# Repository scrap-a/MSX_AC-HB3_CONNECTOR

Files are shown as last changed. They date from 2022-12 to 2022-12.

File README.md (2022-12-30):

# MSX_AC-HB3_CONNECTOR
SONY製（HB-F1など）やPanasonic製（FS-A1など）の一部MSX機種で採用されている、特殊な形状のACアダプタのコネクタ部分について3Dモデルとして試作してみたものです。SONY製の場合のACアダプタの型番はAC-HB3の模様です（未所有）。

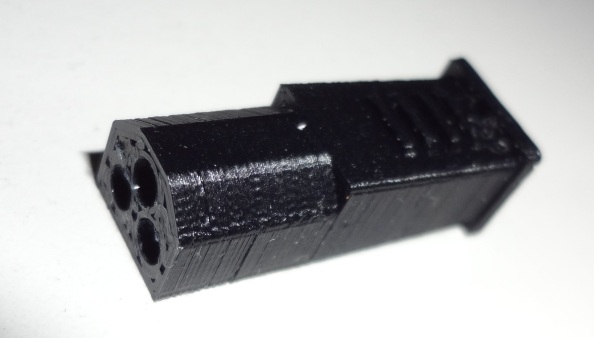
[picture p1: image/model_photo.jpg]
overview image


# 特殊な形状のACアダプタコネクタ
入力電圧（DC9VとAC18Vの両方）も特殊ながら、コネクタが市販されていない形状であり補修が難しいです。

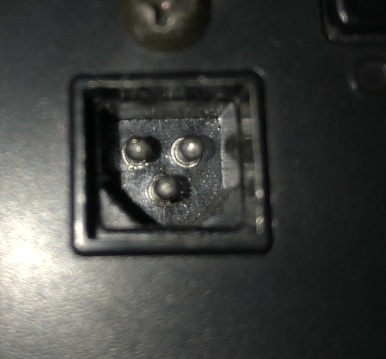
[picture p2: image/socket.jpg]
overview image


# 注意事項
当方は3Dモデリングも3Dプリンタ利用も初めてで、対象のACアダプター自体も所有していないため、形状の測定も設計もいい加減です。<br>
また、3Dプリンタ自体も所有していないので、あまり試行錯誤もできていません。<br>
本モデルを利用してソケット部分が故障したりしても責任は取れません。可能であれば、改善版を共有頂けますとありがたいです。

# 電気的に接続する部分について
AliExpressで購入した2mmΦのバナナプラグ（メス側）を使用しています。<br>
購入したSHOP:https://ja.aliexpress.com/item/4000439855711.html<br>

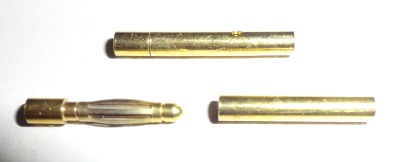
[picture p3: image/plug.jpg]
overview image


精度にバラツキがあるので、ちゃんと受け口にしっかりハマるものを選びます。<br>
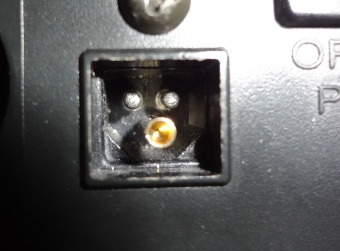
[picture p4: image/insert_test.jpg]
overview image


# モデルについて
OpenSCADで設計しました。srcディレクトリ内にソースも共有しています。モデルのSTLはstlディレクトリにあります。<br>
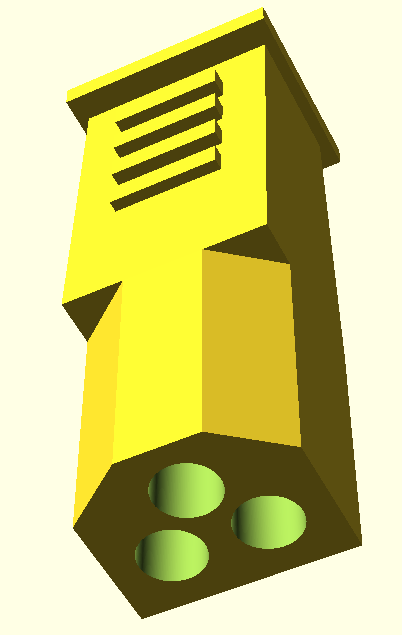
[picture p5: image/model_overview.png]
overview image


穴の部分については、バナナプラグ用の穴と細い穴をつなげて、ケーブルだけが接続できるようにしています。<br>
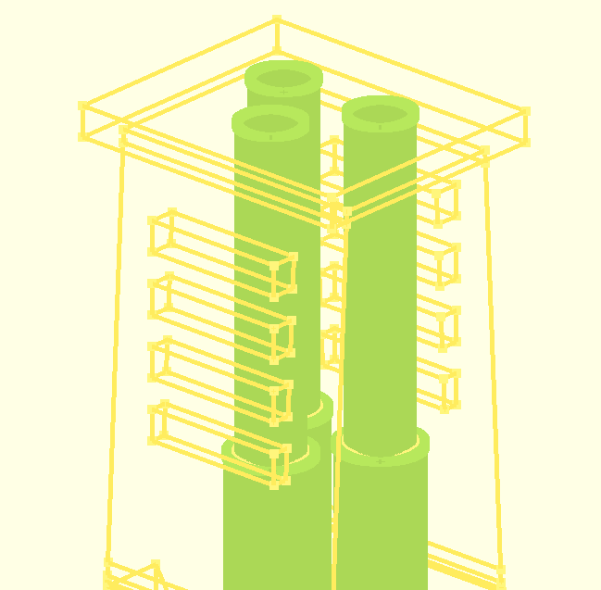
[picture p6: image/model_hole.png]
overview image


緑色がモデルにあいている穴で、下側の太い方がバナナプラグ用です。

# ケーブルなどの接続について
DC9VとAC18Vの電源をどのように準備するか、どのように接続するかなどの説明はしません。あくまでコネクタのモデルを3Dプリントしたあとどのように扱うかの手順です。<br>
1. あらかじめケーブルを通してバナナプラグ（メス側）にはんだ付けします。<br>
このとき3Dプリントしたモデルは熱に弱いので気を付けること。<br>
接合部は、はんだ付けだけでなくレジンなどで固めた方がいいかも知れませんが、はみ出すとモデル部に収まらなくなります。<br>
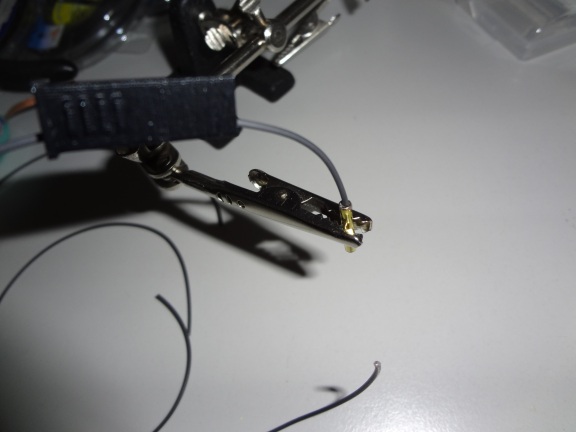
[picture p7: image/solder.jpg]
overview image

2. 穴の部分にバナナプラグを押し込みます。<br>
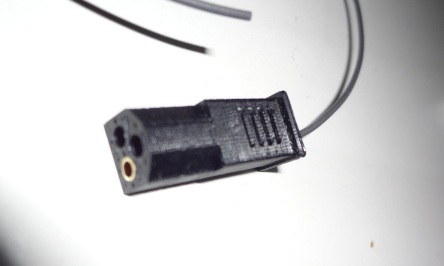
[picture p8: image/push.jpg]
overview image

3. ケーブルを電源プラグの受け口などと接続したら完成です。<br>
必要に応じて接合部を熱収縮チューブで覆うなど処理してください。<br>
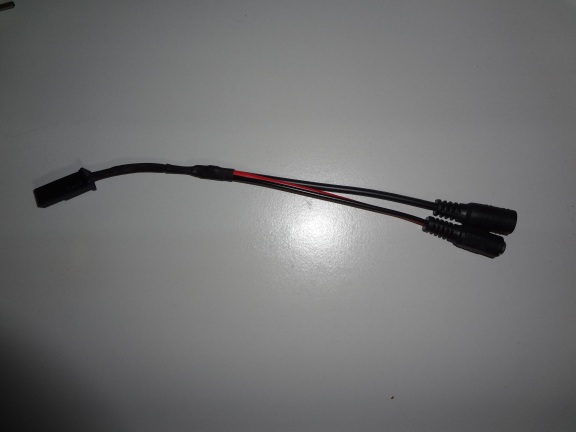
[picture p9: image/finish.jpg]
overview image


# 完成品の画像
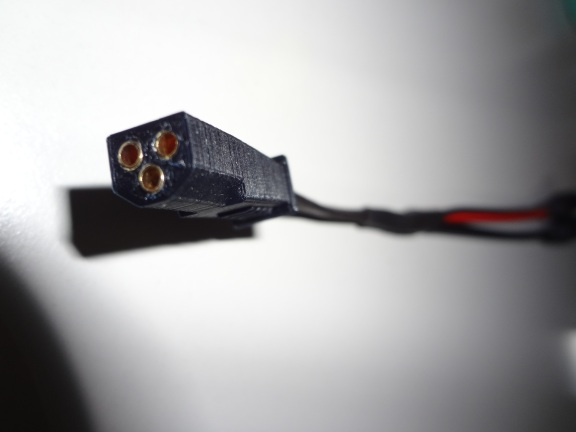
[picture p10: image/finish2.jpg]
overview image

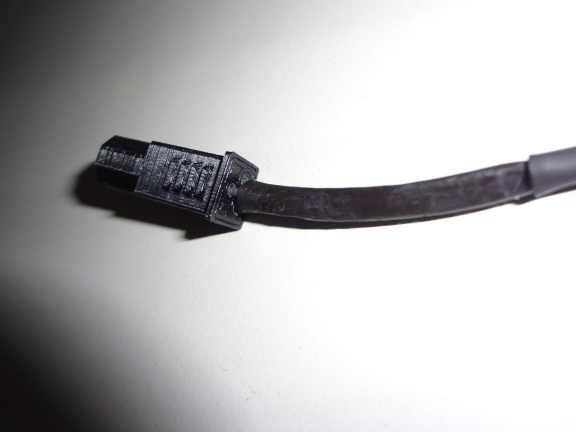
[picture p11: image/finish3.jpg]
overview image

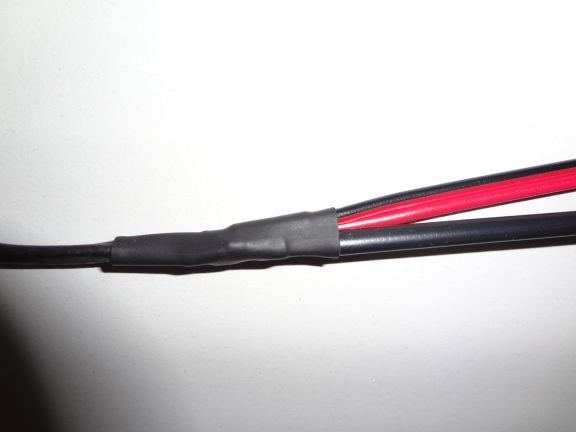
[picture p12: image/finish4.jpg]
overview image

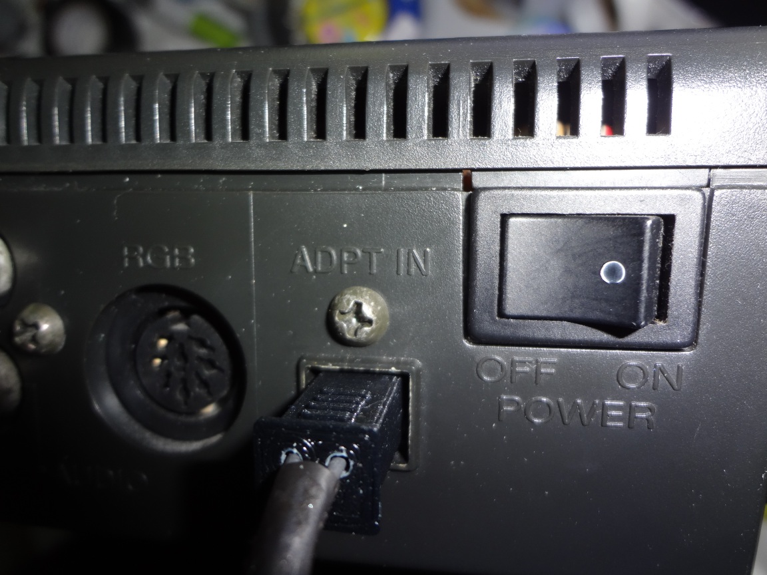
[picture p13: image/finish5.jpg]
overview image

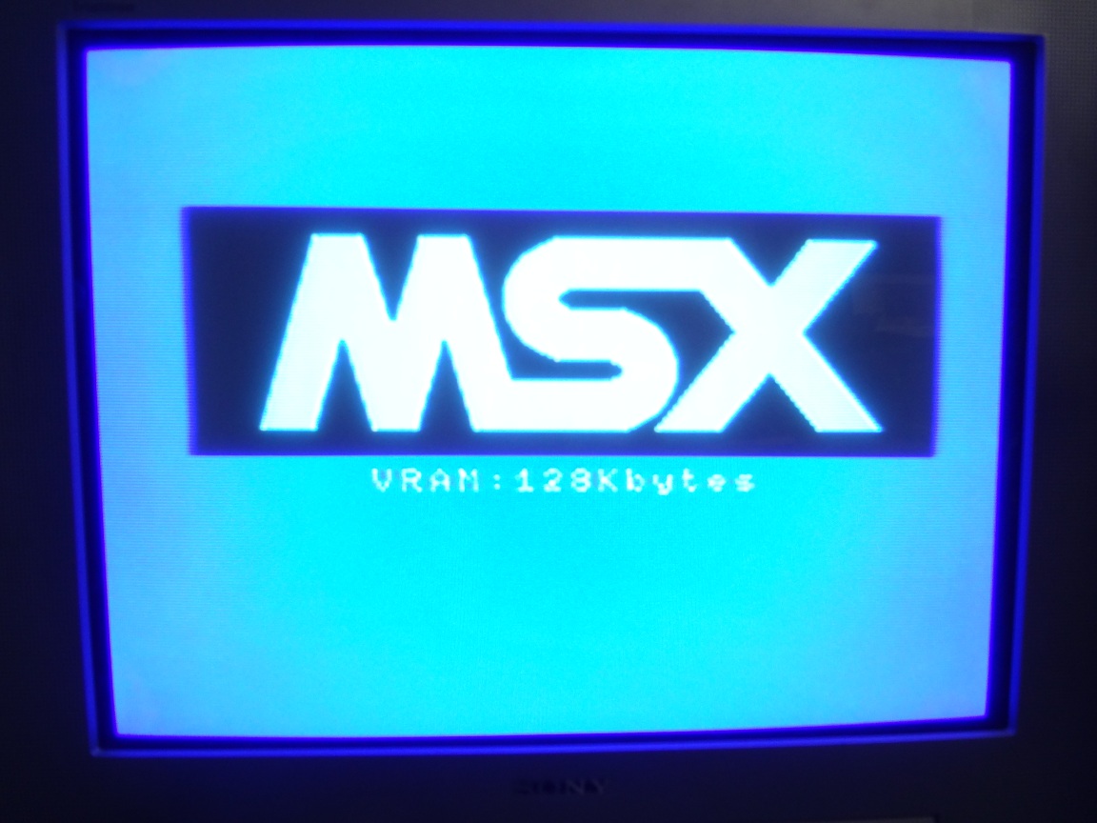
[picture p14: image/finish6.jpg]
overview image


# 参考
下記Blogにてもう少々詳しく書いています。<br>
http://blog.livedoor.jp/scrap_a/archives/32539533.html

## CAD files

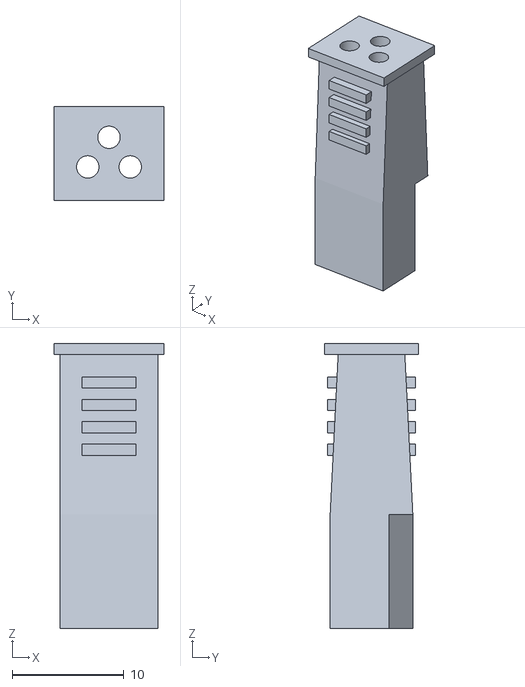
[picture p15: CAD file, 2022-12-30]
stl/msx_ac-hb3_connector.stl
9.80 x 8.40 x 25.5

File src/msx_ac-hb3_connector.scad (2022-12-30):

$fn=360;

h1=25;      //モデルの高さ（除くh5）
h2=15;      //バナナプラグ（メス）の長さ
h3=10.2;    //挿入部モデルの高さ
h4=h1-h3;   //h1-h2
h5=1.0;     //とっかかり部の高さ

t1=0.02;       //バナナプラグ（メス）の入る穴のマージン
d1=2.62+t1;    //穴の入り口は0.01mm広く設計
d2=2.60+t1;    //穴の直径（測定した穴の直径）＋マージン
d3=2.00;       //ケーブル用の小穴直径

t2=0.5;		//プラグサイズx方向の余裕
x0=0.0;
x1=3.0;
x2=6.8;
x3=9.8;

x4=x1;           //穴１のx座標
x5=x2;           //穴2のx座標
x6=(x0+x3)/2;    //穴3のx座標
x7=11.3;      //外の四角の幅

t3=0.5;		//プラグサイズy方向の余裕
y0=0.0;
y1=6.0;
y2=8.4;

y4=3.0;         //穴１のy座標
y5=y4;           //穴2のy座標
y6=5.65;         //穴3のy座標
y7=10.2;        //外の四角の高さ

difference(){
    
    union(){
        //挿入部モデル
        translate([-(x0+x3)/2+t2,-(y0+y2)/2+t3,0])
        resize([x3-2*t2,y2-2*t3,h3])
        linear_extrude(h3){
            polygon([[x0,y0],[x3,y0],[x3,y1],[x2,y2],[x1,y2],[x0,y1]]);
        }

        //取っ手部モデル
        translate([0,0,h3])
        linear_extrude(h4,scale=[1.0,0.8]){
            square([x3-2*t2, y2-2*t3],true);
        }
        
        translate([0,0,h1])
        cube([x3, y2,h5],true);

        translate([0,0,16])
        cube([x3-10*t2, y2-t3,h5],true);
        
        translate([0,0,18])
        cube([x3-10*t2, y2-t3,h5],true);

        translate([0,0,20])
        cube([x3-10*t2, y2-t3,h5],true);
        
        translate([0,0,22])
        cube([x3-10*t2, y2-t3,h5],true);

    }
    
    translate([-(x0+x3)/2,-(y0+y2)/2,0])
    union(){
        translate([x4,y4,0])
        cylinder(h=h2,d1=d1,d2=d2);
        
        translate([x5,y5,0])
        cylinder(h=h2,d1=d1,d2=d2);
        
        translate([x6,y6,0])
        cylinder(h=h2,d1=d1,d2=d2);
    }    
    //ケーブル用の小穴
    translate([-(x0+x3)/2,-(y0+y2)/2,h3])
    union(){
        translate([x4,y4,0])
        cylinder(h=h4+h5,d1=d3);
        
        translate([x5,y5,0])
        cylinder(h=h4+h5,d1=d3);
        
        translate([x6,y6,0])
        cylinder(h=h4+h5,d1=d3);
    }

}
